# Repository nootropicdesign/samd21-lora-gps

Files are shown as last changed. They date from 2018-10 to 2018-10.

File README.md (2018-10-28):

# SAMD21 LoRa GPS Module

This repo has example code for the [SAMD21-based LoRa GPS development board described here](https://nootropicdesign.com/projectlab/2018/10/27/samd21-lora-gps).
This board can be programmed with Arduino as an Arduino Zero. The board uses a SAMD21E18A microcontroller which has fewer pins than the 'G' variant of this chip used on the Arduino Zero, and the Arduino Zero pins used for SPI are not present in this package. The way to get around this is to either define a new Arduino core for this chip variant, or to define a new SPI interface on pins that we do have. I want to program this chip as an ordinary Arduino Zero, so I defined a new SPI interface called `SPI1` according to [this Adafruit tutorial](https://learn.adafruit.com/using-atsamd21-sercom-to-add-more-spi-i2c-serial-ports/creating-a-new-spi).

This required some modifications to certain libraries, described below.

### RadioGPSTest

Simple example demonstrating the use of the Quectel L80 GPS module and HopeRF LoRa module. The files `RHHardwareSPI1.cpp` and `RHHardwareSPI1.h` extend the RadioHead library so that it can use the SPI1 interface defined in the sketch by this code:
```
#ifdef USE_SPI1
SPIClass SPI1(&sercom1, 12, 13, 11, SPI_PAD_0_SCK_1, SERCOM_RX_PAD_3);
RH_RF95 rf95(SS, DIO0, hardware_spi1);
#else
```

Dependencies:

* [RadioHead library](http://www.airspayce.com/mikem/arduino/RadioHead/) - Powerful Arduino library for a variety of radio modules
* [Adafruit GPS library](https://github.com/adafruit/Adafruit_GPS) - Arduino GPS library for NMEA sentence parsing

### LoRaWANTestABP

LoRaWAN node that uses the ABP method of connecting to a gateway. While considered less secure, this method connects much faster and is more reliable.
[See the project description here](https://nootropicdesign.com/projectlab/2018/10/28/lorawan-end-devices/).

Dependencies:

* [arduino-lmic library](https://github.com/nootropicdesign/arduino-lmic) - LoRaWAN stack for embedded devices. This fork of the library has been modified to support the SPI1 interface used by the SAMD21E.
* [CayenneLPP library](https://github.com/sabas1080/CayenneLPP) - Cayenne low-power payload for efficient packing of GPS data into LoRaWAN packets
* [Adafruit GPS library](https://github.com/adafruit/Adafruit_GPS) - Arduino GPS library for NMEA sentence parsing

### LoRaWANTestOTAA

LoRaWAN node that uses the over-the-air activation (OTAA) method of connecting to a gateway.
[See the project description here](https://nootropicdesign.com/projectlab/2018/10/28/lorawan-end-devices/).

* [arduino-lmic library](https://github.com/nootropicdesign/arduino-lmic) - LoRaWAN stack for embedded devices. This fork of the library has been modified to support the SPI1 interface used by the SAMD21E.
* [CayenneLPP library](https://github.com/sabas1080/CayenneLPP) - Cayenne low-power payload for efficient packing of GPS data into LoRaWAN packets
* [Adafruit GPS library](https://github.com/adafruit/Adafruit_GPS) - Arduino GPS library for NMEA sentence parsing

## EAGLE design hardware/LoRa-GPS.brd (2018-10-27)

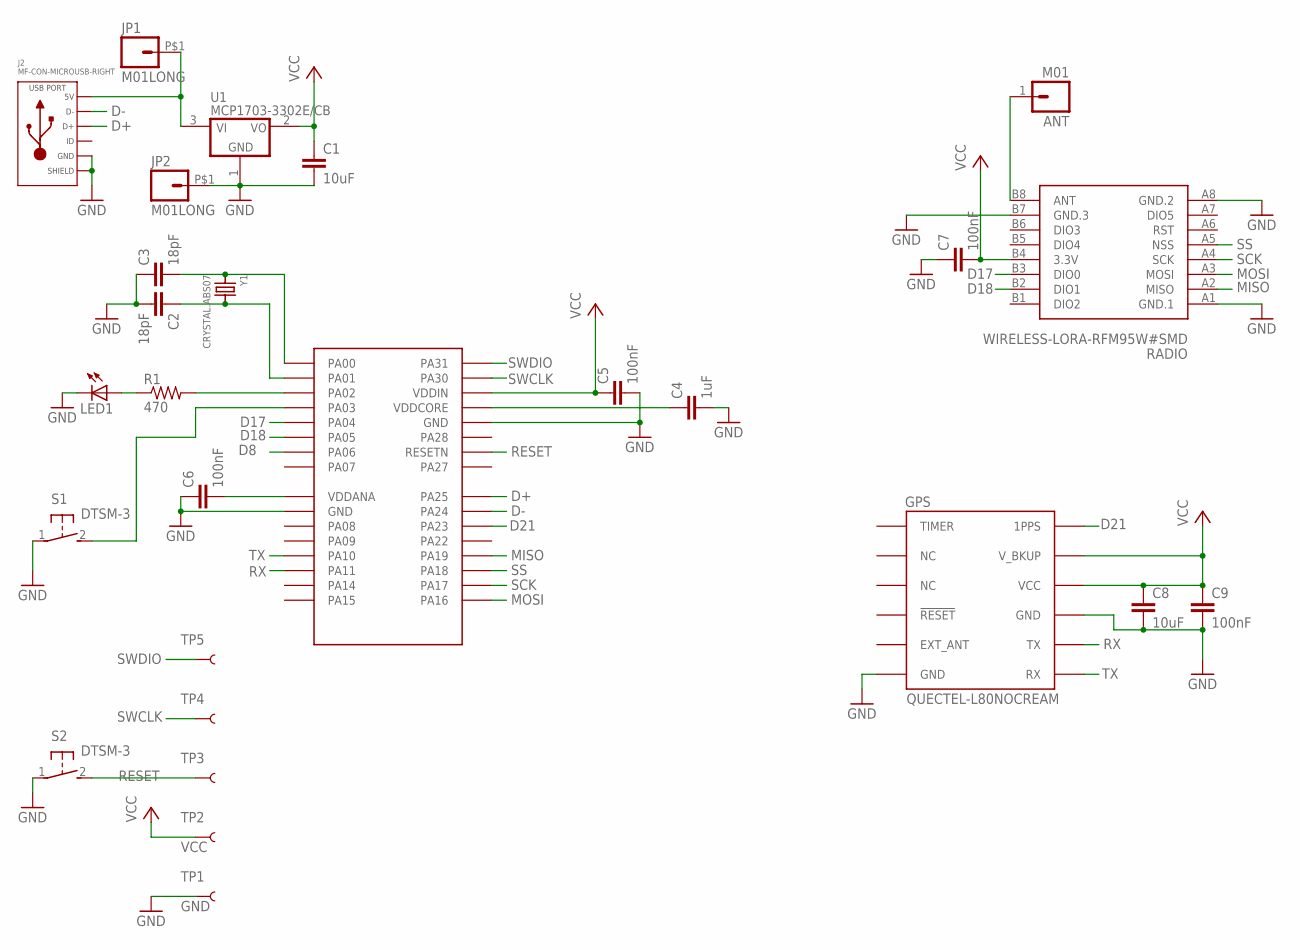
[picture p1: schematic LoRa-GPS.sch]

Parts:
ANT: M01; 1X01
C1, C8: 10uF; C0603-THINCREAM
C2, C3: 18pF; C0603-THINCREAM
C4: 1uF; C0603-THINCREAM
C5, C6, C7, C9: 100nF; C0603-THINCREAM
GPS: QUECTEL-L80NOCREAM; QUECTEL-L80-NOCREAM
J2: MF-CON-MICROUSB-RIGHT; MICROUSB-RIGHT
JP1, JP2: M01LONG; 1X01_LONG
LED1: LEDCHIPLED_0805_THINCREAM; CHIPLED_0805-THINCREAM
R1: 470; R0603-THINCREAM
RADIO: WIRELESS-LORA-RFM95W#SMD
S1, S2: DTSM-3
SAMD21: ATSAMD21E18A-AU; 32-TQFP
TP1: GND; TP_15TH
TP2: VCC; PAD.03X.05
TP3, TP4, TP5: TEST-POINT3X5; PAD.03X.05
U1: MCP1703-3302E/CB; SOT23A_MICROCHIP_CB
Y1: CRYSTAL.ABS07; ABS07

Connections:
ANT: ANT.1, RADIO.B8 (ANT)
D8: SAMD21.7 (PA06)
D17: RADIO.B3 (DIO0), SAMD21.5 (PA04)
D18: RADIO.B2 (DIO1), SAMD21.6 (PA05)
D21: GPS.6 (1PPS), SAMD21.22 (PA23)
D+: J2.3 (D+), SAMD21.24 (PA25)
D-: J2.2 (D-), SAMD21.23 (PA24)
GND: C1.2, C2.2, C3.1, C4.2, C5.2, C6.1, C7.1, C8.2, C9.2, GPS.3 (GND), GPS.12 (GND), J2.5 (GND), J2.S1 (SLD), J2.S2 (SLD), J2.S3 (SLD), J2.S4 (SLD), JP2.P$1, LED1.C, RADIO.A1 (GND.1), RADIO.A8 (GND.2), RADIO.B7 (GND.3), S1.1, S2.1, SAMD21.10 (GND), SAMD21.28 (GND), TP1.P$1, U1.1 (GND)
MISO: RADIO.A2 (MISO), SAMD21.20 (PA19)
MOSI: RADIO.A3 (MOSI), SAMD21.17 (PA16)
unnamed: C6.2, SAMD21.9 (VDDANA)
unnamed: C2.1, SAMD21.2 (PA01), Y1.2
unnamed: C3.2, SAMD21.1 (PA00), Y1.1
unnamed: LED1.A, R1.1
unnamed: C4.1, SAMD21.29 (VDDCORE)
unnamed: R1.2, SAMD21.3 (PA02)
unnamed: S1.2, SAMD21.4 (PA03)
RESET: S2.2, SAMD21.26 (RESETN), TP3.P$1
RX: GPS.2 (TX), SAMD21.14 (PA11)
SCK: RADIO.A4 (SCK), SAMD21.18 (PA17)
SS: RADIO.A5 (NSS), SAMD21.19 (PA18)
SWCLK: SAMD21.31 (PA30), TP4.P$1
SWDIO: SAMD21.32 (PA31), TP5.P$1
TX: GPS.1 (RX), SAMD21.13 (PA10)
VCC: C1.1, C5.1, C7.2, C8.1, C9.1, GPS.4 (VCC), GPS.5 (V_BKUP), RADIO.B4 (3.3V), SAMD21.30 (VDDIN), TP2.P$1, U1.2 (VO)
VIN: J2.1 (5V), JP1.P$1, U1.3 (VI)

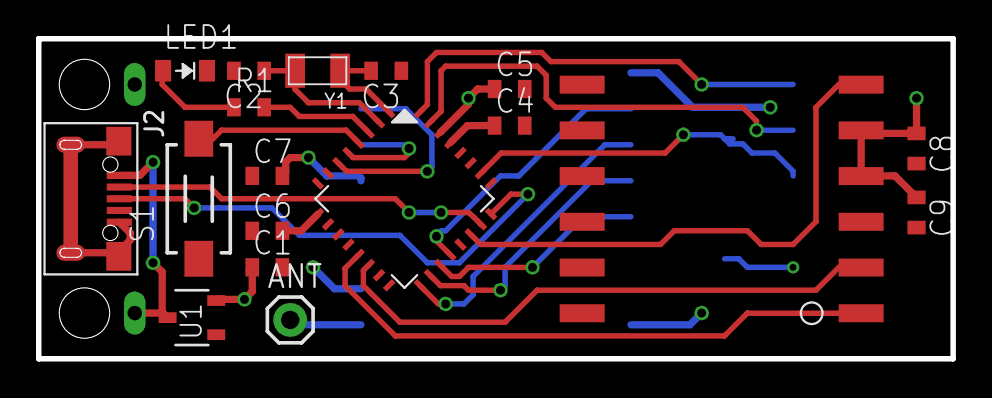
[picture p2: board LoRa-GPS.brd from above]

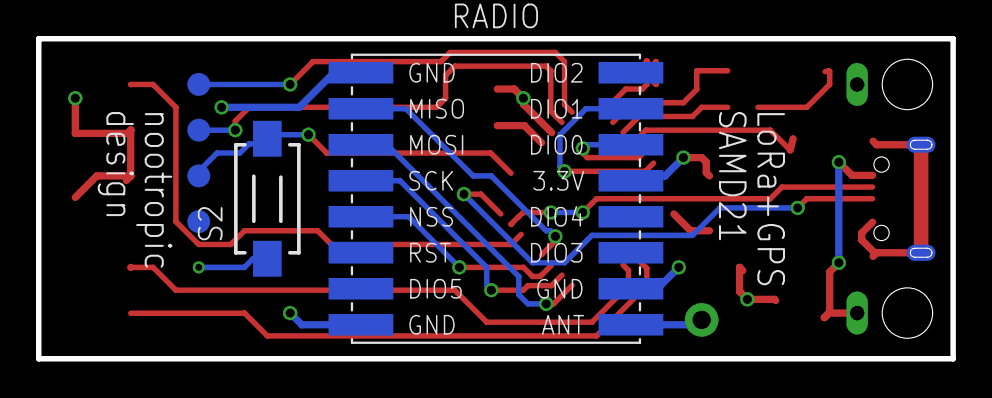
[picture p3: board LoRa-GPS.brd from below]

Board: 2 copper layers, 50.8 x 17.8 mm, 27 parts (6 on the bottom side), 25 nets.

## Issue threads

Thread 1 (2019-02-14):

Created SPI not working

k8zxc, 2019-02-14:
I've tested the LoRaWANTestOTAA.ino in this repo. Also, I created a new SPI following this tutorial: https://learn.adafruit.com/using-atsamd21-sercom-to-add-more-spi-i2c-serial-ports/creating-a-new-spi. I am absolutely a beginner and need a help. Here's my code.

/*******************************************************************************
 * Copyright (c) 2015 Thomas Telkamp and Matthijs Kooijman
 *
 * Permission is hereby granted, free of charge, to anyone
 * obtaining a copy of this document and accompanying files,
 * to do whatever they want with them without any restriction,
 * including, but not limited to, copying, modification and redistribution.
 * NO WARRANTY OF ANY KIND IS PROVIDED.
 *
 * This example sends a valid LoRaWAN packet with payload "Hello,
 * world!", using frequency and encryption settings matching those of
 * the The Things Network.
 *
 * This uses ABP (Activation-by-personalisation), where a DevAddr and
 * Session keys are preconfigured (unlike OTAA, where a DevEUI and
 * application key is configured, while the DevAddr and session keys are
 * assigned/generated in the over-the-air-activation procedure).
 *
 * Note: LoRaWAN per sub-band duty-cycle limitation is enforced (1% in
 * g1, 0.1% in g2), but not the TTN fair usage policy (which is probably
 * violated by this sketch when left running for longer)!
 *
 * To use this sketch, first register your application and device with
 * the things network, to set or generate a DevAddr, NwkSKey and
 * AppSKey. Each device should have their own unique values for these
 * fields.
 *
 * Do not forget to define the radio type correctly in config.h.
 *
 *******************************************************************************/

//#include<Arduino.h>
#include <lmic.h>
#include <hal/hal.h>
#include <SPI.h>
#include "wiring_private.h"

SPIClass SPI1 (&sercom1, 12, 13, 11, SPI_PAD_0_SCK_1, SERCOM_RX_PAD_3);

// LoRaWAN NwkSKey, network session key
// This is the default Semtech key, which is used by the early prototype TTN
// network.
static const PROGMEM u1_t NWKSKEY[16] = { 0x2B, 0x7E, 0x15, 0x16, 0x28, 0xAE, 0xD2, 0xA6, 0xAB, 0xF7, 0x15, 0x88, 0x09, 0xCF, 0x4F, 0x3C };

// LoRaWAN AppSKey, application session key
// This is the default Semtech key, which is used by the early prototype TTN
// network.
static const u1_t PROGMEM APPSKEY[16] = { 0x2B, 0x7E, 0x15, 0x16, 0x28, 0xAE, 0xD2, 0xA6, 0xAB, 0xF7, 0x15, 0x88, 0x09, 0xCF, 0x4F, 0x3C };

// LoRaWAN end-device address (DevAddr)
static const u4_t DEVADDR = 0x03FF0001 ; // <-- Change this address for every node!

// These callbacks are only used in over-the-air activation, so they are
// left empty here (we cannot leave them out completely unless
// DISABLE_JOIN is set in config.h, otherwise the linker will complain).
void os_getArtEui (u1_t* buf) { }
void os_getDevEui (u1_t* buf) { }
void os_getDevKey (u1_t* buf) { }

static uint8_t mydata[] = "Hello, world!";
static osjob_t sendjob;

// Schedule TX every this many seconds (might become longer due to duty
// cycle limitations).
const unsigned TX_INTERVAL = 60;

// Pin mapping
const lmic_pinmap lmic_pins = {
    .nss = 6,
    .rxtx = LMIC_UNUSED_PIN,
    .rst = 5,
    .dio = {2, 3, 4},
};

void onEvent (ev_t ev) {
    SerialUSB.print(os_getTime());
    SerialUSB.print(": ");
    switch(ev) {
        case EV_SCAN_TIMEOUT:
            SerialUSB.println(F("EV_SCAN_TIMEOUT"));
            break;
        case EV_BEACON_FOUND:
            SerialUSB.println(F("EV_BEACON_FOUND"));
            break;
        case EV_BEACON_MISSED:
            SerialUSB.println(F("EV_BEACON_MISSED"));
            break;
        case EV_BEACON_TRACKED:
            SerialUSB.println(F("EV_BEACON_TRACKED"));
            break;
        case EV_JOINING:
            SerialUSB.println(F("EV_JOINING"));
            break;
        case EV_JOINED:
            SerialUSB.println(F("EV_JOINED"));
            break;
        case EV_RFU1:
            SerialUSB.println(F("EV_RFU1"));
            break;
        case EV_JOIN_FAILED:
            SerialUSB.println(F("EV_JOIN_FAILED"));
            break;
        case EV_REJOIN_FAILED:
            SerialUSB.println(F("EV_REJOIN_FAILED"));
            break;
        case EV_TXCOMPLETE:
            SerialUSB.println(F("EV_TXCOMPLETE (includes waiting for RX windows)"));
            if (LMIC.txrxFlags & TXRX_ACK)
              SerialUSB.println(F("Received ack"));
            if (LMIC.dataLen) {
              SerialUSB.println(F("Received "));
              SerialUSB.println(LMIC.dataLen);
              SerialUSB.println(F(" bytes of payload"));
            }
            // Schedule next transmission
            os_setTimedCallback(&sendjob, os_getTime()+sec2osticks(TX_INTERVAL), do_send);
            break;
        case EV_LOST_TSYNC:
            SerialUSB.println(F("EV_LOST_TSYNC"));
            break;
        case EV_RESET:
            SerialUSB.println(F("EV_RESET"));
            break;
        case EV_RXCOMPLETE:
            // data received in ping slot
            SerialUSB.println(F("EV_RXCOMPLETE"));
            break;
        case EV_LINK_DEAD:
            SerialUSB.println(F("EV_LINK_DEAD"));
            break;
        case EV_LINK_ALIVE:
            SerialUSB.println(F("EV_LINK_ALIVE"));
            break;
         default:
            SerialUSB.println(F("Unknown event"));
            break;
    }
}

void do_send(osjob_t* j){
    // Check if there is not a current TX/RX job running
    if (LMIC.opmode & OP_TXRXPEND) {
        SerialUSB.println(F("OP_TXRXPEND, not sending"));
    } else {
        // Prepare upstream data transmission at the next possible time.
        LMIC_setTxData2(1, mydata, sizeof(mydata)-1, 0);
        SerialUSB.println(F("Packet queued"));
    }
    // Next TX is scheduled after TX_COMPLETE event.
}

void setup() {
    SerialUSB.begin(115200);
    SerialUSB.println(F("Starting"));
    SPI1.begin();
    pinPeripheral(11, PIO_SERCOM);
    pinPeripheral(12, PIO_SERCOM);
    pinPeripheral(13, PIO_SERCOM);

    /*
    #ifdef VCC_ENABLE
    // For Pinoccio Scout boards
    pinMode(VCC_ENABLE, OUTPUT);
    digitalWrite(VCC_ENABLE, HIGH);
    delay(1000);
    #endif
    */

    // LMIC init
    os_init();
    // Reset the MAC state. Session and pending data transfers will be discarded.
    LMIC_reset();

    // Set static session parameters. Instead of dynamically establishing a session
    // by joining the network, precomputed session parameters are be provided.
    #ifdef PROGMEM
    // On AVR, these values are stored in flash and only copied to RAM
    // once. Copy them to a temporary buffer here, LMIC_setSession will
    // copy them into a buffer of its own again.
    uint8_t appskey[sizeof(APPSKEY)];
    uint8_t nwkskey[sizeof(NWKSKEY)];
    memcpy_P(appskey, APPSKEY, sizeof(APPSKEY));
    memcpy_P(nwkskey, NWKSKEY, sizeof(NWKSKEY));
    LMIC_setSession (0x1, DEVADDR, nwkskey, appskey);
    #else
    // If not running an AVR with PROGMEM, just use the arrays directly
    LMIC_setSession (0x1, DEVADDR, NWKSKEY, APPSKEY);
    #endif

    #if defined(CFG_eu868)
    // Set up the channels used by the Things Network, which corresponds
    // to the defaults of most gateways. Without this, only three base
    // channels from the LoRaWAN specification are used, which certainly
    // works, so it is good for debugging, but can overload those
    // frequencies, so be sure to configure the full frequency range of
    // your network here (unless your network autoconfigures them).
    // Setting up channels should happen after LMIC_setSession, as that
    // configures the minimal channel set.
    // NA-US channels 0-71 are configured automatically
    LMIC_setupChannel(0, 868100000, DR_RANGE_MAP(DR_SF12, DR_SF7),  BAND_CENTI);      // g-band
    LMIC_setupChannel(1, 868300000, DR_RANGE_MAP(DR_SF12, DR_SF7B), BAND_CENTI);      // g-band
    LMIC_setupChannel(2, 868500000, DR_RANGE_MAP(DR_SF12, DR_SF7),  BAND_CENTI);      // g-band
    LMIC_setupChannel(3, 867100000, DR_RANGE_MAP(DR_SF12, DR_SF7),  BAND_CENTI);      // g-band
    LMIC_setupChannel(4, 867300000, DR_RANGE_MAP(DR_SF12, DR_SF7),  BAND_CENTI);      // g-band
    LMIC_setupChannel(5, 867500000, DR_RANGE_MAP(DR_SF12, DR_SF7),  BAND_CENTI);      // g-band
    LMIC_setupChannel(6, 867700000, DR_RANGE_MAP(DR_SF12, DR_SF7),  BAND_CENTI);      // g-band
    LMIC_setupChannel(7, 867900000, DR_RANGE_MAP(DR_SF12, DR_SF7),  BAND_CENTI);      // g-band
    LMIC_setupChannel(8, 868800000, DR_RANGE_MAP(DR_FSK,  DR_FSK),  BAND_MILLI);      // g2-band
    // TTN defines an additional channel at 869.525Mhz using SF9 for class B
    // devices' ping slots. LMIC does not have an easy way to define set this
    // frequency and support for class B is spotty and untested, so this
    // frequency is not configured here.
    #elif defined(CFG_us915)
    // NA-US channels 0-71 are configured automatically
    // but only one group of 8 should (a subband) should be active
    // TTN recommends the second sub band, 1 in a zero based count.
    // https://github.com/TheThingsNetwork/gateway-conf/blob/master/US-global_conf.json
    LMIC_selectSubBand(1);
    #endif

    // Disable link check validation
    LMIC_setLinkCheckMode(0);

    // TTN uses SF9 for its RX2 window.
    LMIC.dn2Dr = DR_SF9;

    // Set data rate and transmit power for uplink (note: txpow seems to be ignored by the library)
    LMIC_setDrTxpow(DR_SF7,14);

    // Start job
    do_send(&sendjob);
}

void loop() {
    os_runloop_once();
}

nootropicdesign, 2019-02-14:
What hardware are you trying to use this code on? The use of the alternative SPI definition is due to the fact that I built a custom board that did not have the primary SPI pins available, as defined by the Arduino Zero core. You should not need an alternative SPI SERCOM.

k8zxc, 2019-02-15:
The schematic of our development board is attached below.

We burned the Arduino Zero bootloader into it. The default SPI pins of zero were:

PA12 D22 / MISO SERCOM2.0 SERCOM4.0
PB10 D23 / MOSI SERCOM4.2
PB11 D24 / SCK SERCOM4.3

and we leave them unconnected. In the schematic, we used the pins 11, 12, and 13 of the Arduino for SPI knowing that muxing of SERCOM is possible.

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

nootropicdesign, 2019-02-15:
Which lmic library are you using? I created a fork that uses a different definition of SPI so that it works with the pins I used: https://github.com/nootropicdesign/arduino-lmic

Why did you comment out the #include of Arduino.h?

I do not know if my definitions of the SPI interface will work with the chip you are using. I used the SAMD21E, not the G.

k8zxc, 2019-02-16:
Thank you so much, Sir.

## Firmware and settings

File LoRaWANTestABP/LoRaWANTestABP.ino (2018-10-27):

#include <lmic.h>
#include <hal/hal.h>
#include <SPI.h>
#include <CayenneLPP.h>
#include <Adafruit_GPS.h>

#define LED 14
#define BUTTON 42
#define PPS 21
#define Serial SerialUSB
#define UNCONFIRMED 0
#define CONFIRMED 1
#define FIX_BLINK_DELAY 1000
Adafruit_GPS GPS(&Serial1);
boolean DEBUG = false;
boolean connected = false;
boolean sendLocation = true;
unsigned long lastBlink;

void blink(uint8_t n);
void do_send(osjob_t* j);

// Network Session Key, Application Session Key, and Device Address are provided by The Things Network when you create a device.
// Take care to specify these in most-significant-bit (MSB) format.

// MSB
static u1_t PROGMEM NWKSKEY[16] = { 0x00, 0x00, 0x00, 0x00, 0x00, 0x00, 0x00, 0x00, 0x00, 0x00, 0x00, 0x00, 0x00, 0x00, 0x00, 0x00 };
// MSB
static u1_t PROGMEM APPSKEY[16] = { 0x00, 0x00, 0x00, 0x00, 0x00, 0x00, 0x00, 0x00, 0x00, 0x00, 0x00, 0x00, 0x00, 0x00, 0x00, 0x00 };
static u4_t DEVADDR = 0x00000000;


// These callbacks are only used in over-the-air activation, so they are
// left empty here (we cannot leave them out completely unless
// DISABLE_JOIN is set in config.h, otherwise the linker will complain).
void os_getArtEui (u1_t* buf) { }
void os_getDevEui (u1_t* buf) { }
void os_getDevKey (u1_t* buf) { }


//static uint8_t mydata[] = "Hello, world!";
static osjob_t sendjob;

CayenneLPP lpp(51);

// Schedule TX every this many seconds (might become longer due to duty
// cycle limitations).
const unsigned TX_INTERVAL = 30;

// LMIC pin definitions for the SAMD21E board used as an Arduino Zero. SS is pin 10, DIO are pins 17 and 18.
const lmic_pinmap lmic_pins = {
    .nss = 10,
    .rxtx = LMIC_UNUSED_PIN,
    .rst = LMIC_UNUSED_PIN,
    .dio = {17, 18, LMIC_UNUSED_PIN},
};

void onEvent (ev_t ev) {
    Serial.print(os_getTime());
    Serial.print(": ");
    switch(ev) {
        case EV_SCAN_TIMEOUT:
            Serial.println(F("EV_SCAN_TIMEOUT"));
            break;
        case EV_BEACON_FOUND:
            Serial.println(F("EV_BEACON_FOUND"));
            break;
        case EV_BEACON_MISSED:
            Serial.println(F("EV_BEACON_MISSED"));
            break;
        case EV_BEACON_TRACKED:
            Serial.println(F("EV_BEACON_TRACKED"));
            break;
        case EV_JOINING:
            Serial.println(F("EV_JOINING"));
            break;
        case EV_JOINED:
            Serial.println(F("EV_JOINED"));
            // Disable link check validation (automatically enabled
            // during join, but not supported by TTN at this time).
            LMIC_setLinkCheckMode(0);
            connected = true;
            break;
        case EV_RFU1:
            Serial.println(F("EV_RFU1"));
            break;
        case EV_JOIN_FAILED:
            Serial.println(F("EV_JOIN_FAILED"));
            break;
        case EV_REJOIN_FAILED:
            Serial.println(F("EV_REJOIN_FAILED"));
            break;
        case EV_TXCOMPLETE:
            Serial.println(F("EV_TXCOMPLETE"));
            if (LMIC.txrxFlags & TXRX_ACK)
              Serial.println(F("Received ack"));
            if (LMIC.dataLen) {
              Serial.println(F("Received "));
              Serial.println(LMIC.dataLen);
              Serial.println(F(" bytes of payload"));
            }
            // Schedule next transmission
            os_setTimedCallback(&sendjob, os_getTime()+sec2osticks(TX_INTERVAL), do_send);
            break;
        case EV_LOST_TSYNC:
            Serial.println(F("EV_LOST_TSYNC"));
            break;
        case EV_RESET:
            Serial.println(F("EV_RESET"));
            break;
        case EV_RXCOMPLETE:
            // data received in ping slot
            Serial.println(F("EV_RXCOMPLETE"));
            break;
        case EV_LINK_DEAD:
            Serial.println(F("EV_LINK_DEAD"));
            break;
        case EV_LINK_ALIVE:
            Serial.println(F("EV_LINK_ALIVE"));
            break;
         default:
            Serial.println(F("Unknown event"));
            break;
    }
}

void do_send(osjob_t* j){
    // Check if there is not a current TX/RX job running
    if (LMIC.opmode & OP_TXRXPEND) {
      Serial.println(F("OP_TXRXPEND, not sending"));
    } else {
      // Prepare upstream data transmission at the next possible time.
      lpp.reset();
      if (GPS.fix && sendLocation) {
        Serial.print("lat = ");
        Serial.print(GPS.latitudeDegrees);
        Serial.print("  lon = ");
        Serial.print(GPS.longitudeDegrees);
        Serial.print("  alt = ");
        Serial.print(GPS.altitude);
        Serial.println();
        lpp.addGPS(1, GPS.latitudeDegrees, GPS.longitudeDegrees, GPS.altitude);
      } else {
        lpp.addPresence(2, 1);
      }
      blink(3);
      LMIC_setTxData2(2, lpp.getBuffer(), lpp.getSize(), CONFIRMED);
    }
    // Next TX is scheduled after TX_COMPLETE event.
}

void initGPS() {
  GPS.begin(115200);
  GPS.sendCommand(PMTK_SET_NMEA_OUTPUT_RMCGGA);
  //GPS.sendCommand(PMTK_SET_NMEA_UPDATE_1HZ);
  GPS.sendCommand(PMTK_SET_NMEA_UPDATE_200_MILLIHERTZ); // every 5 seconds
  GPS.sendCommand("$PQTXT,W,0,0*22"); // disable GPTXT messages
}

void updateLED() {
  unsigned long now = millis();
  if ((GPS.fix) && (sendLocation) && ((now - lastBlink) > FIX_BLINK_DELAY)) {
    lastBlink = now;
    digitalWrite(LED, HIGH);
    delay(50);
    digitalWrite(LED, LOW);
  }
}

void blink(uint8_t n) {
  for(uint8_t i=0;i<n;i++) {
    digitalWrite(LED, HIGH);
    delay(50);
    digitalWrite(LED, LOW);
    delay(50);
  }
}

void setup() {
  pinMode(BUTTON, INPUT_PULLUP);
  pinMode(PPS, INPUT);
  pinMode(LED, OUTPUT);
  while ((!Serial) && (digitalRead(BUTTON) == HIGH)) {
    digitalWrite(LED, HIGH);
    delay(10);
    digitalWrite(LED, LOW);
    delay(30);
  }

  digitalWrite(LED, HIGH);
  delay(200);
  digitalWrite(LED, LOW);
  delay(1000);

  lastBlink = millis();

  initGPS();

  // LMIC init
  os_init();
  // Reset the MAC state. Session and pending data transfers will be discarded.
  LMIC_reset();
  LMIC_setClockError(MAX_CLOCK_ERROR * 1 / 100);


  Serial.println("using ABP...");
  LMIC_setSession (0x1, DEVADDR, NWKSKEY, APPSKEY);
  LMIC_selectSubBand(1);
  // Disable link check validation
  LMIC_setLinkCheckMode(0);

  // TTN uses SF9 for its RX2 window.
  LMIC.dn2Dr = DR_SF9;

  // Set data rate and transmit power for uplink (note: txpow seems to be ignored by the library)
  LMIC_setDrTxpow(DR_SF7,23);
  connected = true;

  // Start job (sending automatically starts OTAA too)
  do_send(&sendjob);
}

void loop() {
  os_runloop_once();
  GPS.read();
  if (GPS.newNMEAreceived()) {
    if (DEBUG) Serial.print(GPS.lastNMEA());
    GPS.parse(GPS.lastNMEA());
  }
  updateLED();
  if (digitalRead(BUTTON) == LOW) {
    unsigned long pressed = millis();
    while (digitalRead(BUTTON) == LOW) {
      if ((millis() - pressed) > 1000) {
        sendLocation = !sendLocation;
        break;
      }
    }
    os_clearCallback(&sendjob);
    do_send(&sendjob);
  }

}

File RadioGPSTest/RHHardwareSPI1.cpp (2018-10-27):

// RHHardwareSPI1.h
// Author: Mike McCauley (mikem@airspayce.com)
// Copyright (C) 2011 Mike McCauley
// Contributed by Joanna Rutkowska
// $Id: RHHardwareSPI1.cpp,v 1.19 2018/01/06 23:50:45 mikem Exp mikem $

#include <RHHardwareSPI1.h>
#include "wiring_private.h"

// Declare a single default instance of the hardware SPI interface class
RHHardwareSPI1 hardware_spi1;

#ifdef RH_HAVE_HARDWARE_SPI

RHHardwareSPI1::RHHardwareSPI1(Frequency frequency, BitOrder bitOrder, DataMode dataMode)
    :
    RHGenericSPI(frequency, bitOrder, dataMode)
{
}

uint8_t RHHardwareSPI1::transfer(uint8_t data)
{
    return SPI1.transfer(data);
}

void RHHardwareSPI1::attachInterrupt()
{
#if (RH_PLATFORM == RH_PLATFORM_ARDUINO || RH_PLATFORM == RH_PLATFORM_NRF52)
    SPI1.attachInterrupt();
#endif
}

void RHHardwareSPI1::detachInterrupt()
{
#if (RH_PLATFORM == RH_PLATFORM_ARDUINO || RH_PLATFORM == RH_PLATFORM_NRF52)
    SPI1.detachInterrupt();
#endif
}

void RHHardwareSPI1::begin()
{
    // Perhaps this is a uniform interface for SPI?
    // Currently Teensy and ESP32 only
   uint32_t frequency;
   if (_frequency == Frequency16MHz)
       frequency = 16000000;
   else if (_frequency == Frequency8MHz)
       frequency = 8000000;
   else if (_frequency == Frequency4MHz)
       frequency = 4000000;
   else if (_frequency == Frequency2MHz)
       frequency = 2000000;
   else
       frequency = 1000000;

#if ((RH_PLATFORM == RH_PLATFORM_ARDUINO) && defined (__arm__) && (defined(ARDUINO_SAM_DUE) || defined(ARDUINO_ARCH_SAMD))) || defined(ARDUINO_ARCH_NRF52)
    // Arduino Due in 1.5.5 has its own BitOrder :-(
    // So too does Arduino Zero
    ::BitOrder bitOrder;
#else
    uint8_t bitOrder;
#endif

   if (_bitOrder == BitOrderLSBFirst)
       bitOrder = LSBFIRST;
   else
       bitOrder = MSBFIRST;

    uint8_t dataMode;
    if (_dataMode == DataMode0)
	dataMode = SPI_MODE0;
    else if (_dataMode == DataMode1)
	dataMode = SPI_MODE1;
    else if (_dataMode == DataMode2)
	dataMode = SPI_MODE2;
    else if (_dataMode == DataMode3)
	dataMode = SPI_MODE3;
    else
	dataMode = SPI_MODE0;

    // Save the settings for use in transactions
   _settings = SPISettings(frequency, bitOrder, dataMode);
   SPI1.begin();
   pinPeripheral(11, PIO_SERCOM);
   pinPeripheral(12, PIO_SERCOM);
   pinPeripheral(13, PIO_SERCOM);
}

void RHHardwareSPI1::end()
{
    return SPI1.end();
}

void RHHardwareSPI1::beginTransaction()
{
#if defined(SPI_HAS_TRANSACTION)
    SPI1.beginTransaction(_settings);
#endif
}

void RHHardwareSPI1::endTransaction()
{
#if defined(SPI_HAS_TRANSACTION)
    SPI1.endTransaction();
#endif
}

void RHHardwareSPI1::usingInterrupt(uint8_t interrupt)
{
#if defined(SPI_HAS_TRANSACTION)

#endif
}

#endif

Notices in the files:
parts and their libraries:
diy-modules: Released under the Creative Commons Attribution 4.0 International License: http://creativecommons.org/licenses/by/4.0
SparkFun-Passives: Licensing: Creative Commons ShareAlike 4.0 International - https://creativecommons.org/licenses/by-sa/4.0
